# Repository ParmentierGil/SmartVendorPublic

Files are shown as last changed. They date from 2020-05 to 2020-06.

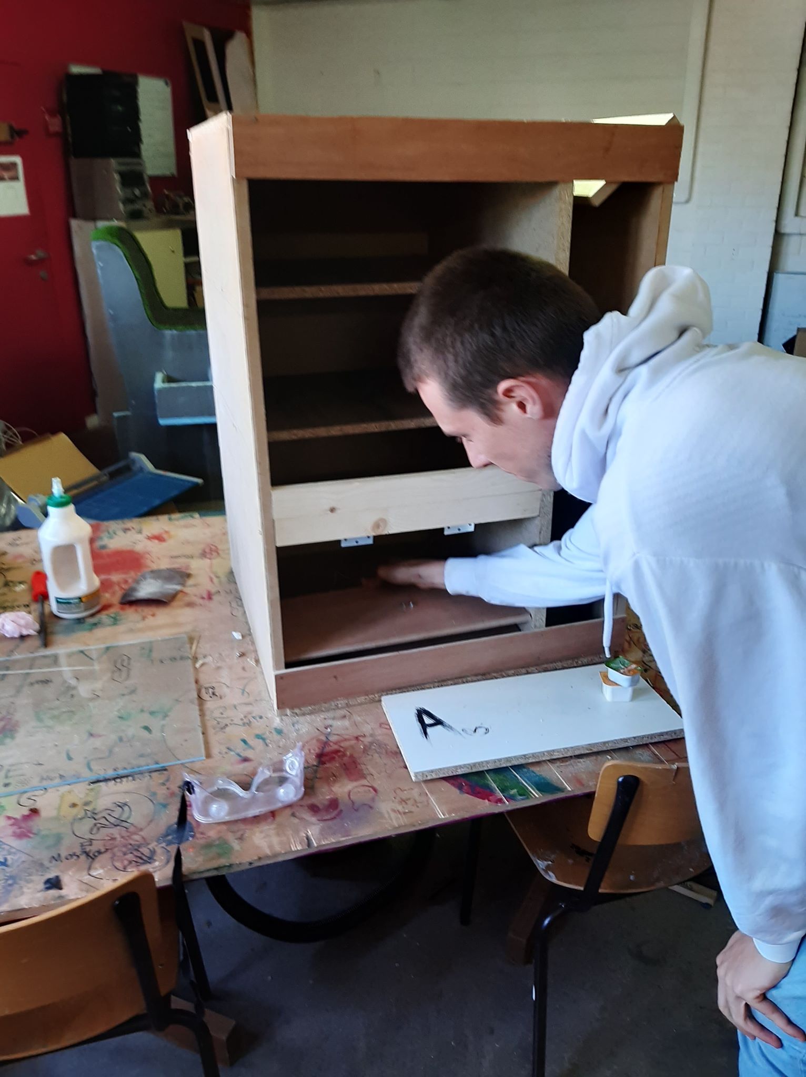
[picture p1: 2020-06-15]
Constructie/103668261_3239586569426355_2421695507440351485_n.jpg

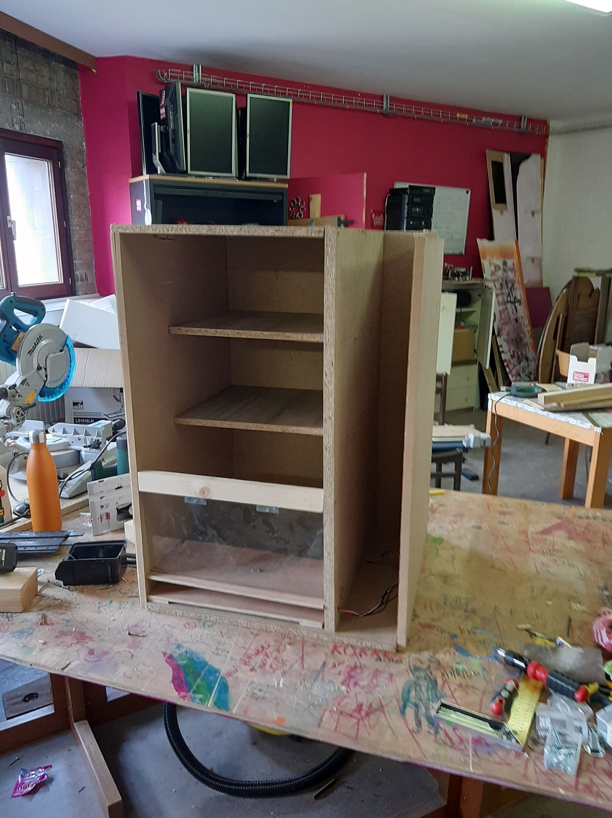
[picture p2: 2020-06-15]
Constructie/102950625_278225840040048_7201117200041064750_n.jpg

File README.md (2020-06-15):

# Smart Vendor - Project 1

Voor Project 1 maakte ik een snackautomaat met een admin website. Het automaat zelf is gemaakt uit hout met plexiglazen deur en productluik. Als sensors is er een gewichtsensor onderaan het apparaat om te bevestigen dat het product gevallen is, een thermometer om de temperatuur in kaart te brengen, een muntstuk acceptor om met cash munten te betalen en een keypad om de selectie te maken van het product. 

Als actuators heb ik gebruik gemaakt van enkele motors die verbonden zijn met spiralen om de producten te laten vallen. Verder is er nog een LCD scherm om het ingestoken geld alsook de ingedrukte toetsen weer te geven. Voor de afwerking is het automaat zwart geschilderd en zijn er leds om de producten beter te zien. 

Dit alles wordt bestuurd door middel van een Raspberry Pi met python scripts. Op deze Raspberry Pi draait ook de webserver die de admin website weergeeft. Op deze site krijg je als homepage een dashboard waar de status van het automaat en de sensors wordt weergegeven. Ook vind je op de homepage de indeling van de producten in het apparaat terug. Verder is er nog een pagina waar de producten aangepast en verwijderd kunnen worden. Zo kan er eenvoudig met een ander product in het automaat worden gestoken.

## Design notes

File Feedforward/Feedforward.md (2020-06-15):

# Projectgegevens
**VOORNAAM NAAM:**  Gil Parmentier

**Sparringpartner:** Gilles De Muynck

**Projectsamenvatting in max 10 woorden:** Snackautomaat met valbevestiging en admin website

**Projecttitel:** Smart Vendor

# Tips voor feedbackgesprekken
## Voorbereiding

>Bepaal voor jezelf waar je graag feedback op wil. Schrijf op voorhand een aantal punten op waar je zeker feedback over wil krijgen. Op die manier zal het feedbackgesprek gerichter verlopen en zullen vragen, die je zeker beantwoord wil hebben, aan bod komen.

## Tijdens het gesprek:
>**Luister actief:** Schiet niet onmiddellijk in de verdediging maar probeer goed te luisteren. Laat verbaal en non-verbaal ook zien dat je aandacht hebt voor de feedback door een open houding (oogcontact, rechte houding), door het maken van aantekeningen, knikken...

>**Maak notities:** Schrijf de feedback op zo heb je ze nog nadien. Noteer de kernwoorden en zoek naar een snelle noteer methode voor jezelf. Als je goed noteert,kan je op het einde van het gesprek je belangrijkste feedback punten kort overlopen.

>**Vat samen:** Wacht niet op een samenvatting door de docenten, dit is jouw taak: Check of je de boodschap goed hebt begrepen door actief te luisteren en samen te vatten in je eigen woorden.

>**Sta open voor de feedback:** Wacht niet op een samenvatting door de docenten, dit is jouw taak: Check of je de boodschap goed hebt begrepen door actief te luisteren en samen te vatten in je eigen woorden.`

>**Denk erover na:** Denk na over wat je met de feedback gaat doen en koppel terug. Vind je de opmerkingen terecht of onterecht? Herken je je in de feedback? Op welke manier ga je dit aanpakken?

## NA HET GESPREK

> Herlees je notities en maak actiepunten. Maak keuzes uit alle feedback die je kreeg: Waar kan je mee aan de slag en wat laat je even rusten. Wat waren de prioriteiten? Neem de opdrachtfiche er nog eens bij om je focuspunten te bepalen. Noteer je actiepunten op de feedbackfiche.

# Feedforward gesprekken

## Gesprek 1 (Datum: 03/06/2020)
Lector: Hans Ameel

Vragen voor dit gesprek:
- [x] vraag 1: Hoe kan ik de pulses die mijn muntstukacceptor doorstuurt beter opvangen?

Dit is de feedback op mijn vragen. 
- feedback 1 Gebruik een adapter die een hogere Amperage heeft.
- feedback 2 Gebruik een simpelere loop die niet teveel cycles overneemt van mn pulse detection

Hier komt de feedforward: wat ga ik concreet doen?
- [ ] ToDo 1 Nieuwe 12V adapter bestellen
- [ ] ToDo 2 Code versimpelen

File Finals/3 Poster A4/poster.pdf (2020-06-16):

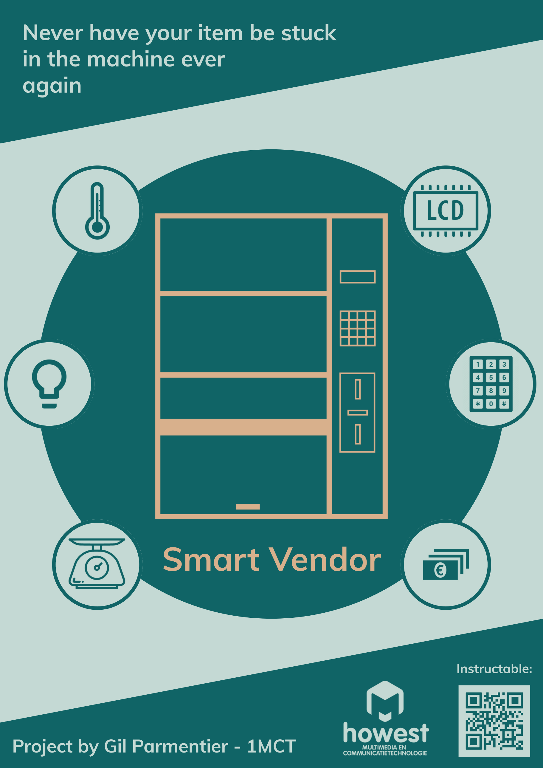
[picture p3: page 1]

## SmartVendor

Instructable:

ProjectbyGilParmentier-1MCT

Neverhaveyouritem bestuck
inthemachineever
again

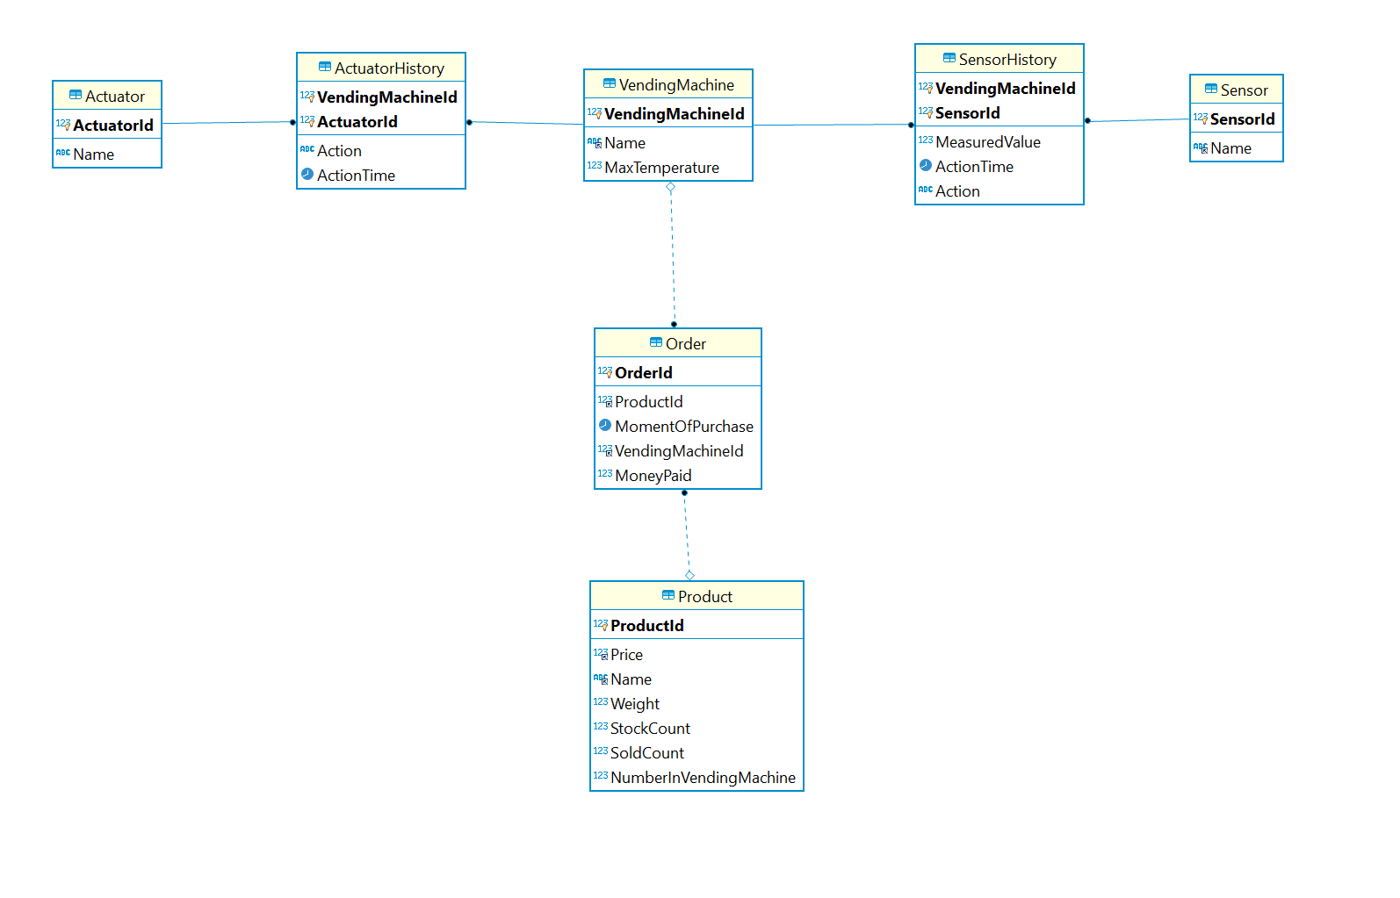
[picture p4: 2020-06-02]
Code/Database-export/ERD-4.png

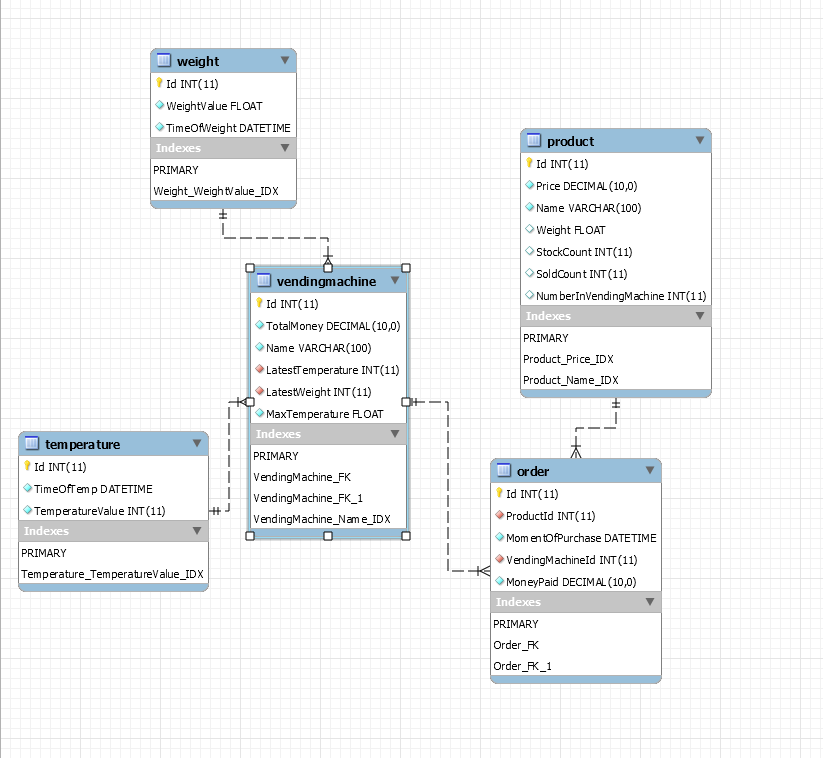
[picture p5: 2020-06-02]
Code/Database-export/ERD-2.png

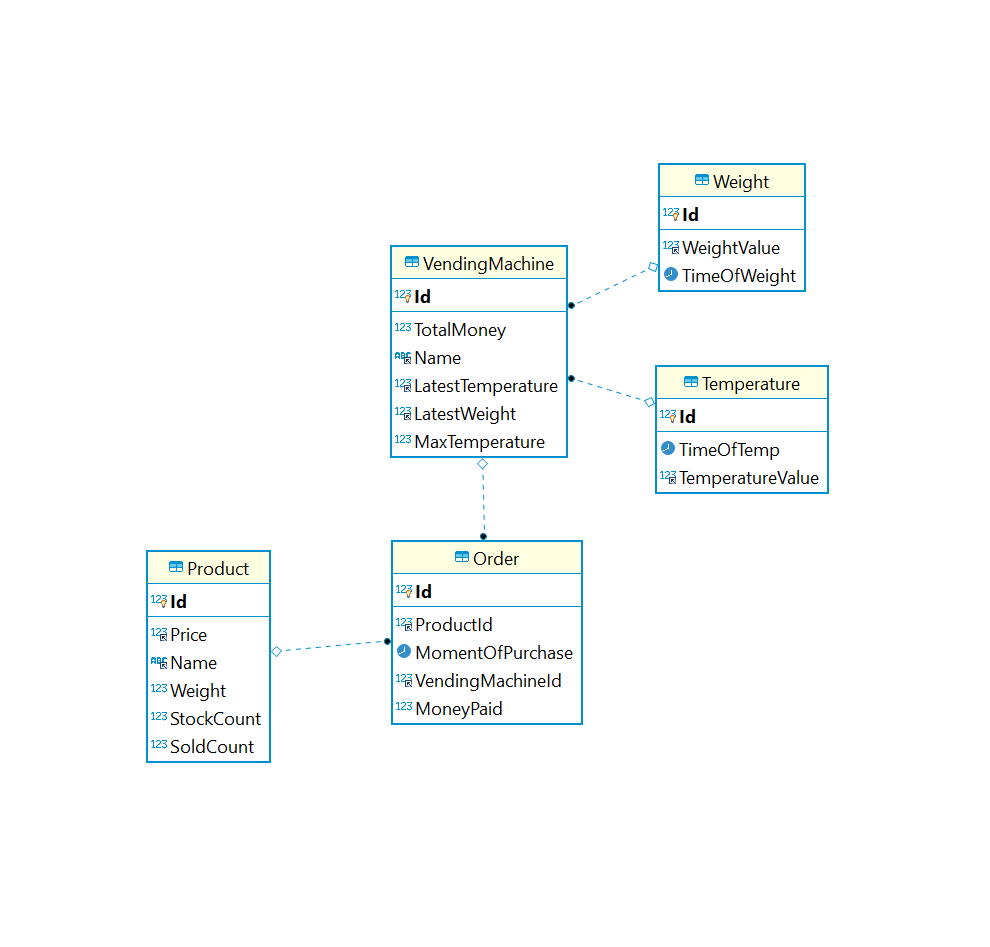
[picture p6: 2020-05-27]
Code/Database-export/ERD-1.png

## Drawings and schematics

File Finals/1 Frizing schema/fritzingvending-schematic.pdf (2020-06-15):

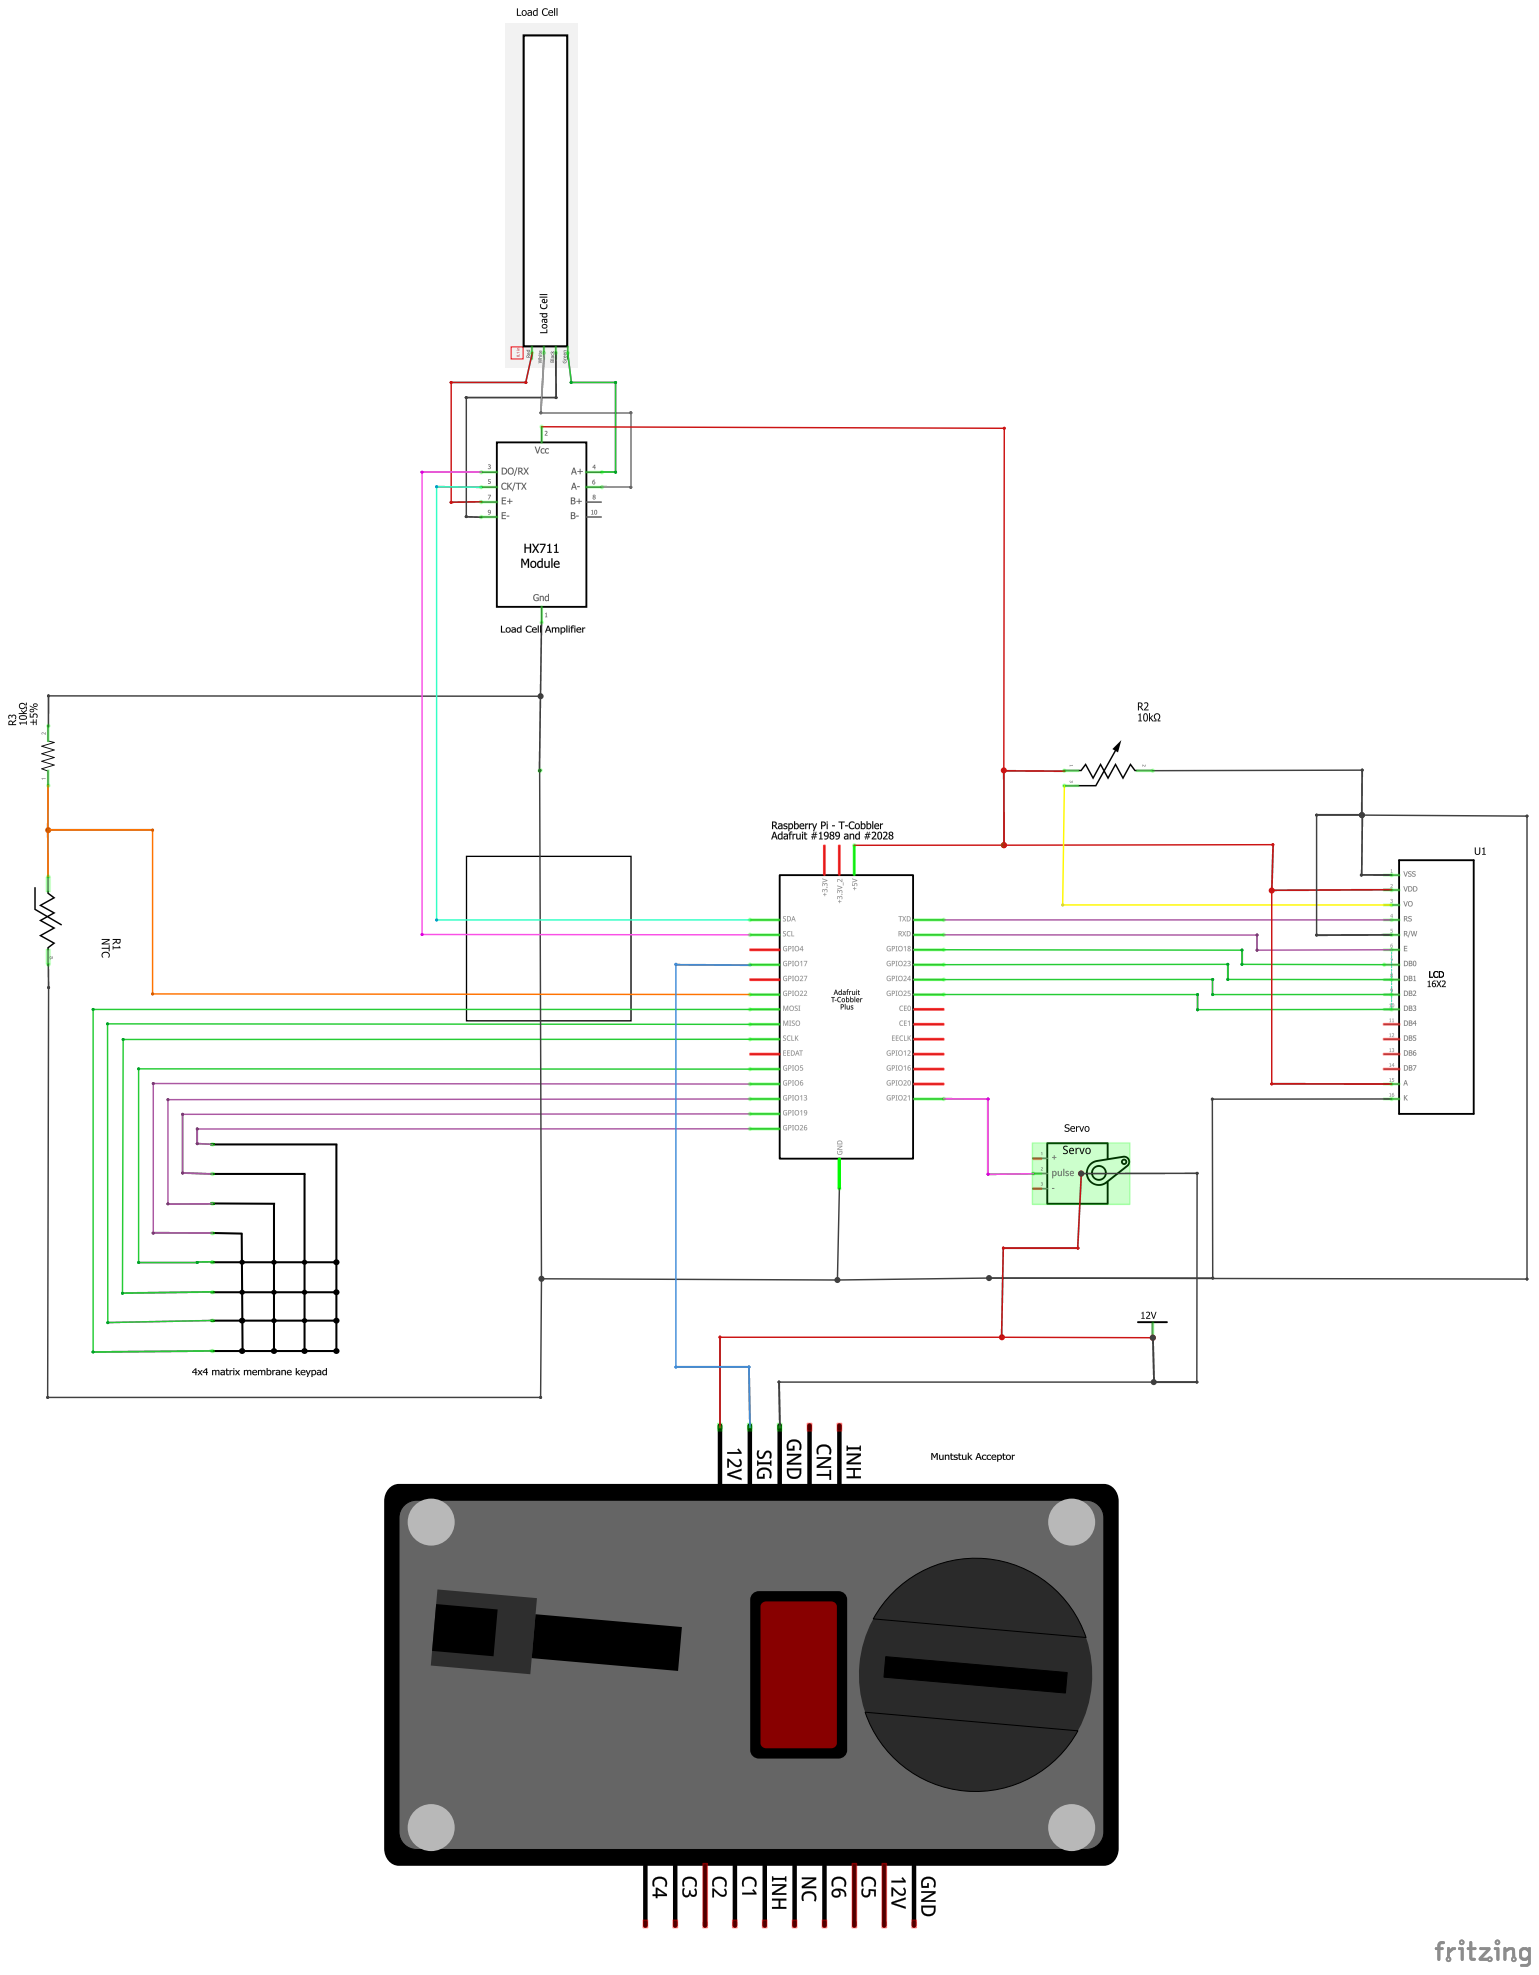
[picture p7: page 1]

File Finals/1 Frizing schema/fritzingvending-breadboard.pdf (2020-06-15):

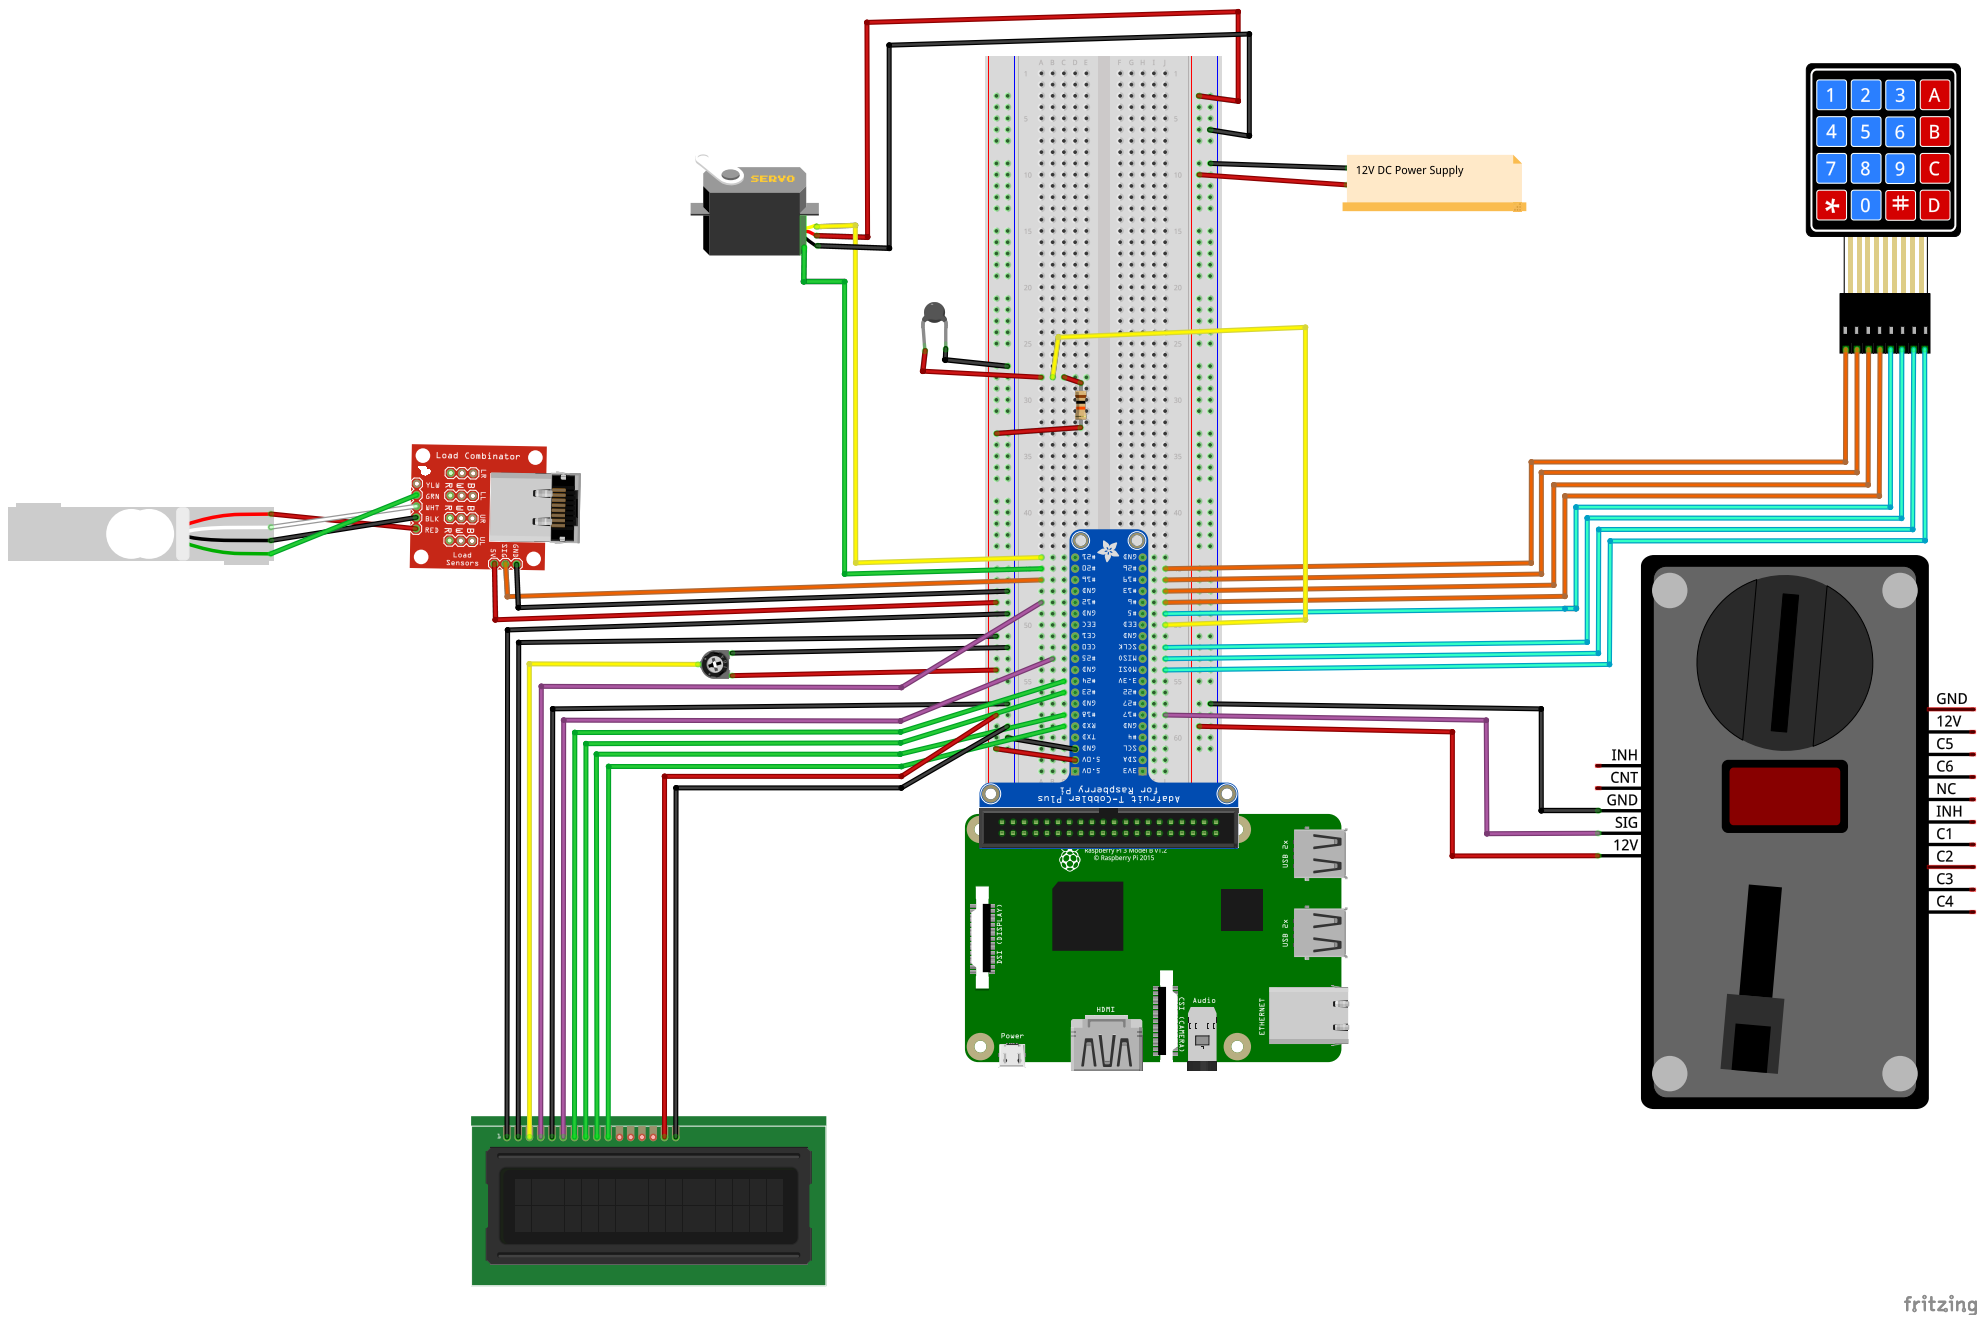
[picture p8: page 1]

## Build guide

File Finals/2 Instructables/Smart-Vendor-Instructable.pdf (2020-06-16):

instructables

Vending Machine With Scale to Confirm Itemdrop (Raspberry Pi) (http://www.instructables.com/id/Smart-Vendor/)

by TajMahaladeen (http://www.instructables.com/member/TajMahaladeen/)

Welcome fellow maker,

for a school project I decided to make a snack vending machine. Our assignment was to create a recreatable device that used at least 3 sensors and 1 actuator. I went to make a vending machine partly because I had access to some essential parts (i.e. the motors) via my local makerslab. First o# the idea was to create a beverage vending machine, but that wouldn't have been feasible because of the need of isolation, cooling element and softer release mechanism for sparkling beverages.

This project was a &rst for me in some ways; I had never worked with wood and electronics before on such a scale. My experience was primarily in software, so I decided to challenge myself by creating a project that would be a real learning experience.

I will try to explain to you guys, in the best way possible, how to create this vending machine. Bear in mind all this was a &rst for me, so I made some rookie mistakes with woodcutting etc.

All code can be found in the Github repository: https://github.com/ParmentierGil/SmartVendorPublic

Supplies:

Vending Machine With Scale to Confirm Itemdrop (Raspberry Pi): Page 1

Wood
Hinges
2 harder ones for the main door 2 soft ones for the product hatch

Plexiglass
4 vending machine DC motors (with a button for rotation managment) 4 spirals (I used 6 mm² copper electrical wire)
4 connectors to connect the motors the spiral (I 3D printed them) Raspberry Pi
4x4 Keypad
Coin acceptor
LCD
Jumper wires
Breadboards
4 TIP 120 transistors
Resistors
One wire thermometer
LED strip

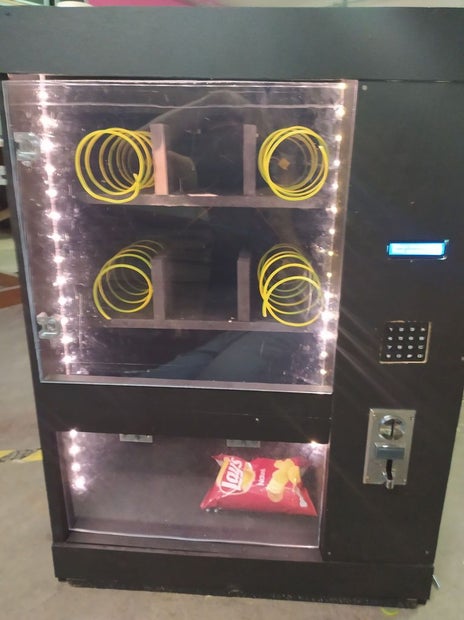
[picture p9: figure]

Vending Machine With Scale to Confirm Itemdrop (Raspberry Pi): Page 2

### Step 1: Programming the Sensors

### Step 2: Connecting and Programming the Motors

Since I had the most experience in software I decided to start with the programming of the sensors &rst.

The sensors include:

One wire thermometer
Load cell sensor
4x4 keypad
Coin acceptor

The one wire thermometer is pretty straight forward and just involves connecting the one wire to GPIO PIN 4 of the Raspberry Pi (with some resistors) and reading the &le associated with it.

The load cell was somewhat more complicated but still quiet easy. The 4 wires had to be connected to the HX711 ampli&er and in turn the HX711 ampli&er had to be connected to the Raspberry Pi. Once this has been done, I used the HX711 python library to read out values. Reading out the load cell without load de&ned the tare value. After that I placed some pre-known weights on the scale and with the rule of three I calculated the constant that the read value had to be divided by to be presented by a value in grams.

The 4x4 keypad is as intuitive as it can be. With the 8 wires connected to the keypad representing the 4 columns and 4 rows of the keypad. Some caution has be had with the ordering of these wires, since the 2 4x4 keypads I used had 2 totally di#erent wire orders. With an easy to use keypad library the pressed key can easily be registered when wired correctly to the Raspberry Pi.

The hardest of the sensors is de&nitely the coin acceptor. Setting up the coins on the device is pretty straight forward due to some good documentation. I had a device which was capable of di#erentiating 4 di#erent coins. You have to specify the associated amount of pulses for a coin the device sends to the Raspberry Pi. The coin registration on the device end is almost Fawless which can be seen by the display on the side. The problem lays in registering these pulses on the Raspberry Pi. A powerful enough adapter (12V, 1A) has to be used to be able to distinctively register the di#erent coins, as well as some careful programming to not stop counting pulses too early.

Vending Machine With Scale to Confirm Itemdrop (Raspberry Pi): Page 3

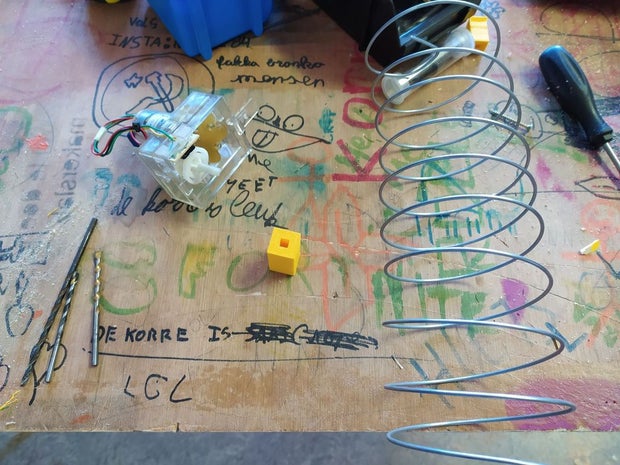
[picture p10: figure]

### Step 3: Creating the Housing of the Machine

I scavenged some vending machine motors from my local makerslab, but I still needed to &gure out how to connect and program them.

The motors had 4 wires connected to them and after some &guring out 2 were for power (at least 12V) and 2 were for the button which is pressed every half a turn. I connected each of these motors to a TIP 120 transistor to be able to control them via the Raspberry Pi. One of the other 2 wires I connected to a input of the Pi (with pullup resistor) and one to ground.

After that I made some spirals from 2.2mm steel wire, which turned out to be spiraling the wrong way; so that my items went backwards instead. So I used 6mm² copper electrical wire which was way easier to work with.

After making 4 spiral it was time to make the connectors necessary to connect to spiral to the motors. I decided to 3D print them (&le attached) and glue them to the motors and bend the wire around them.

For the housing I used wood that was present in the makerslab. Since there wasn't plenty of one type and the front panel had to be slimmer to &t the electronics, the housing consisted of at least 6 types of wood.

First o# I sawed 2 planks of 168 x 58 cm in half for the backpanel, the 2 side panels and the middle divider panel.

For the bottom panel I used a convenient (or so I thought) piece of wood of 58 x 58 cm. This turned to out to be a mistake since I didn't account for the thickness of the wood, so the backpanel had to be screwed in on top of the bottom panel and the side panels had to be screwed in from the side. This left an extra 2 cm piece sticking out of the top.

After that I screwed the 2 horizontal product planks to the middle divider panel. Aswell as the top of the product compartment. Then I started breaking up the plexi glass for the hatch which I connected with 2 soft hinges on to a bar of wood connected to the middel divider panel. Once that was completed the hole middle compartment had to be screwed in to the left side panel.

Then I made the wooden parts of the scale and glued them to the bottom of the housing. This left a bit of a gap on the bottom of the housing which I solved with placing a thin plank in front. (Not on picture)

Vending Machine With Scale to Confirm Itemdrop (Raspberry Pi): Page 4

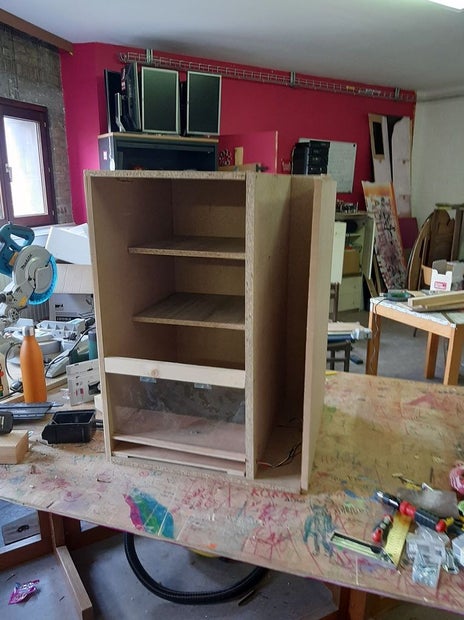
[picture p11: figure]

### Step 4: Assembling the Sensors and Motors to the Housing

### Step 5: Finished Up the Vending Machine

Once the skeleton of the housing was done it was
time to insert the guts.

First I cut some holes in a plank for the LCD, the keypad and the coin acceptor. Then I nailed these electronics to the plank and wired them to the Raspberry Pi. Some careful planning had to be done to not cross the wires to much. The one wire thermometer I connected to a breadboard glued on the inside of the electronics plank. Then I sawed a plank for the Raspberry Pi, the breadboard for the motor transistors and the arduino which I used to supply the 12V for the coin acceptor and the motors.

The motors I glued to the horizontal product planks and I added some vertical planks to divide the item compartments.

For the &nish I painted the whole machine black and added a LED strip to the inside. Under the coin acceptor I made a little compartment for the coins to fall in, so they wouldn't slide all over the left compartment. I also added in the plexiglass door with the harder hinges.

Vending Machine With Scale to Confirm Itemdrop (Raspberry Pi): Page 5

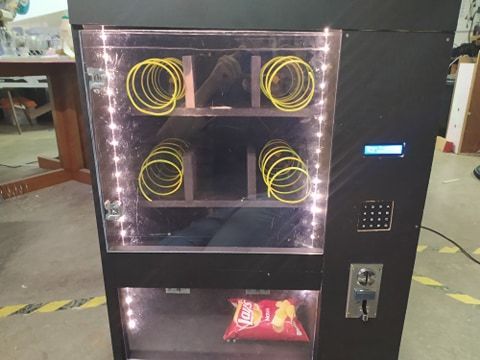
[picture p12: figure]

Vending Machine With Scale to Confirm Itemdrop (Raspberry Pi): Page 6

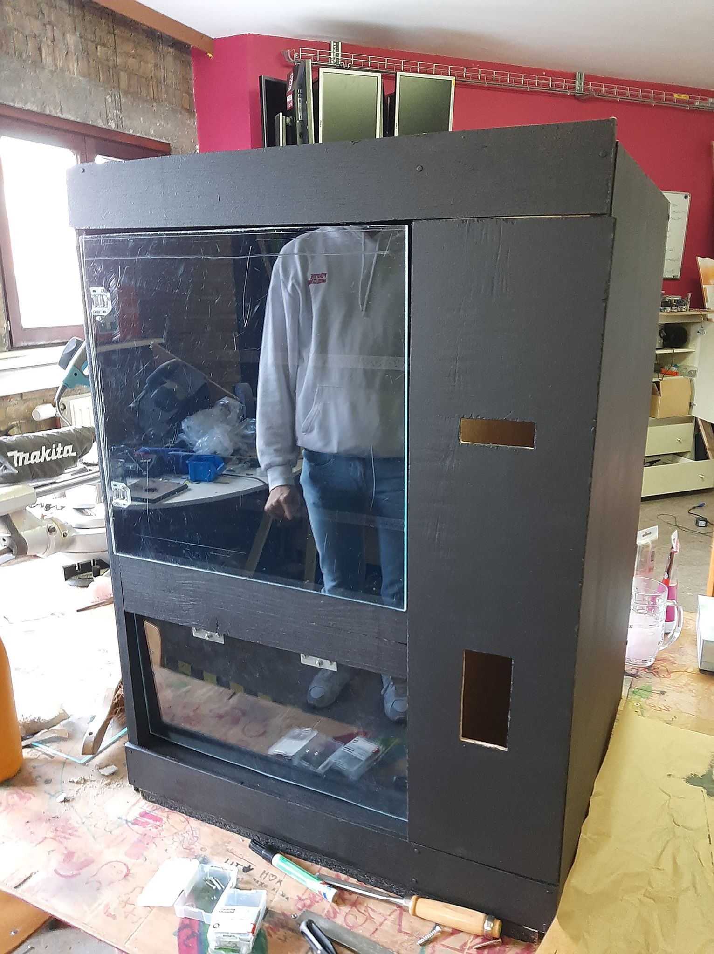
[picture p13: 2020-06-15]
Constructie/103847829_598746871049662_8595658446078185828_n.jpg

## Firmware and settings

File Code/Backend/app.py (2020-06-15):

# pylint: skip-file
from repositories.DataRepository import DataRepository
from helpers.TempSensor import TempSensor
from helpers.LCD import LCD
from helpers.Keypad import Keypad
from helpers.MuntstukAcceptor import MuntstukAcceptor
from helpers.LoadCell import LoadCell
from helpers.Motor import Motor
from flask import Flask, jsonify, request
from flask_socketio import SocketIO
from flask_cors import CORS
from flask_script import Manager, Server
from RPi import GPIO

import time
import json
import threading
import multiprocessing as mp
import queue

message_queue = queue.Queue()

one_wire_file_name = "/sys/bus/w1/devices/28-60818f1d64ff/w1_slave"
one_wire_file = open(one_wire_file_name, 'r')

GPIO.setwarnings(False)
GPIO.setmode(GPIO.BCM)

app = Flask(__name__)
app.config['SECRET_KEY'] = 'Hier mag je om het even wat schrijven, zolang het maar geheim blijft en een string is'

socketio = SocketIO(app, cors_allowed_origins="*")
CORS(app)


def print_messages_from_threads():
    message = message_queue.get()
    while True:
        print(message)
        message = message_queue.get()


t = threading.Thread(target=print_messages_from_threads)
t.start()

# API ENDPOINTS


@app.route('/')
def hallo():
    return 'niets'

@app.route('/api/v1/status')
def status():
    status = DataRepository.get_status()
    return jsonify(status)

@app.route('/api/v1/products')
def products():
    products = DataRepository.get_all_products()
    return jsonify(products)

@app.route('/api/v1/product/<id>', methods=['DELETE', 'PUT'])
def product(id):
    if request.method == 'DELETE':
        deleted = DataRepository.delete_product(id)
        return jsonify(deleted)
    elif request.method == 'PUT':
        data = json.loads(request.data)
        print(data)
        try:
            product = DataRepository.update_product(data)
            print(product)
            return jsonify(id)
        except:
            return jsonify("failed")

@app.route('/api/v1/products/inmachine')
def products_in_machine():
    products = DataRepository.get_products_in_machine()
    return jsonify(products)

@app.route('/api/v1/totalmoney')
def total_money():
    money = DataRepository.get_total_money()
    return jsonify(money)

@app.route('/api/v1/lastorder')
def last_order():
    order = DataRepository.get_last_order()
    return jsonify(order)


# SOCKET IO
@socketio.on('connected')
def page_connected(msg):
    print(msg)
    socketio.emit('status_changed', 1)
    socketio.emit('return_on_connect', 'Succesfully connected to backend')


top_left_motor = Motor(20, 21)
top_right_motor = Motor(12, 16)
bottom_left_motor = Motor(14, 22)
bottom_right_motor = Motor(15, 2)
motors = {"top_left": top_left_motor, "top_right": top_right_motor,
          "bottom_left": bottom_left_motor, "bottom_right": bottom_right_motor}

lcd = LCD()
one_wire_temp_sensor = TempSensor(socketio, message_queue)
muntstuk_acceptor = MuntstukAcceptor(message_queue, lcd)
load_cell = LoadCell(lcd)
keypad = Keypad(socketio, lcd, muntstuk_acceptor, load_cell, motors)

lcd.setDaemon(True)
one_wire_temp_sensor.setDaemon(True)
muntstuk_acceptor.setDaemon(True)
keypad.setDaemon(True)



if __name__ == '__main__':
    try:
        DataRepository.set_status(1)
        lcd.start()
        one_wire_temp_sensor.start()
        keypad.start()
        muntstuk_acceptor.start()
        print("Current Thread count: %i." % threading.active_count())
        socketio.run(app, debug=False, host='0.0.0.0', port=5500)
    except:
        GPIO.cleanup()
        DataRepository.set_status(0)

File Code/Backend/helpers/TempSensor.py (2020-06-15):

import time
current_milli_time = lambda: int(round(time.time() * 1000))
from threading import Thread, Lock
from repositories.DataRepository import DataRepository

one_wire_file_name = "/sys/bus/w1/devices/28-60818f1d64ff/w1_slave"
one_wire_file = open(one_wire_file_name, 'r')

class TempSensor(Thread):
    def __init__(self, socket, message_queue):
        Thread.__init__(self)
        self.socket = socket
        self.message_queue = message_queue
        self.last_temp_reading_time = 0
        self.temp_reading_delta = 60000
    def run(self):
        try:
            while True:
                if current_milli_time() > (self.last_temp_reading_time + self.temp_reading_delta):
                    self.read_temperature()
                    self.last_temp_reading_time = current_milli_time()
        except:
            one_wire_file.close()

        finally:
            one_wire_file.close()

    def read_temperature(self):
        for line in one_wire_file:
            if 't=' in line:
                temp_index = line.index('t=') + 2
                temp = line[temp_index:]
                self.message_queue.put(temp)
                DataRepository.update_temperature(temp)
                self.socket.emit("new_temp", temp)
        one_wire_file.seek(0)
    

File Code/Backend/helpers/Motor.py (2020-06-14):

import RPi.GPIO as GPIO
import threading
import time

RELEASE_REVOLUTIONS = 2

class Motor(threading.Thread):
    def __init__(self, write_pin, read_pin):
        threading.Thread.__init__(self)
        self.motor_write_pin = write_pin
        self.motor_read_pin = read_pin
        self.gpio_setup()
        self.revolutions = 0

    def gpio_setup(self):   
        GPIO.setwarnings(False)
        GPIO.setmode(GPIO.BCM)
        if self.motor_read_pin == 2:
            GPIO.setup(self.motor_read_pin, GPIO.IN)
        else:
            GPIO.setup(self.motor_read_pin, GPIO.IN, pull_up_down = GPIO.PUD_UP)
        GPIO.setup(self.motor_write_pin, GPIO.OUT)
        GPIO.output(self.motor_write_pin, 0)

    def release_item(self):
        GPIO.output(self.motor_write_pin, 1)
        item_released = 0
        last_status = 1

        while not item_released:
            status = GPIO.input(self.motor_read_pin)

            if status == 1 and last_status == 0:
                self.revolutions += 0.5

            if self.revolutions == RELEASE_REVOLUTIONS:
                GPIO.output(self.motor_write_pin, 0)   
                print("Item released!")
                self.revolutions = 0
                item_released = 1        
            
            last_status = status
            time.sleep(0.1)

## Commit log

2020-05-26 One wire temp sensor reading and saving
2020-05-26 Sensor classes, threading working socket and product selection
2020-06-02 Load cell, buy flow
2020-06-14 Frontend. Motor update
